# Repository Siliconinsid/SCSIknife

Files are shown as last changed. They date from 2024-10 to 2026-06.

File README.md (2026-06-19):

# SCSIknife

SCSIknife - A compact and versatile SCSI emulator.

SCSIknife is a ZuluSCSI™ PICO OSHW derivative, compatible with the ZuluSCSI™ PICO firmware.

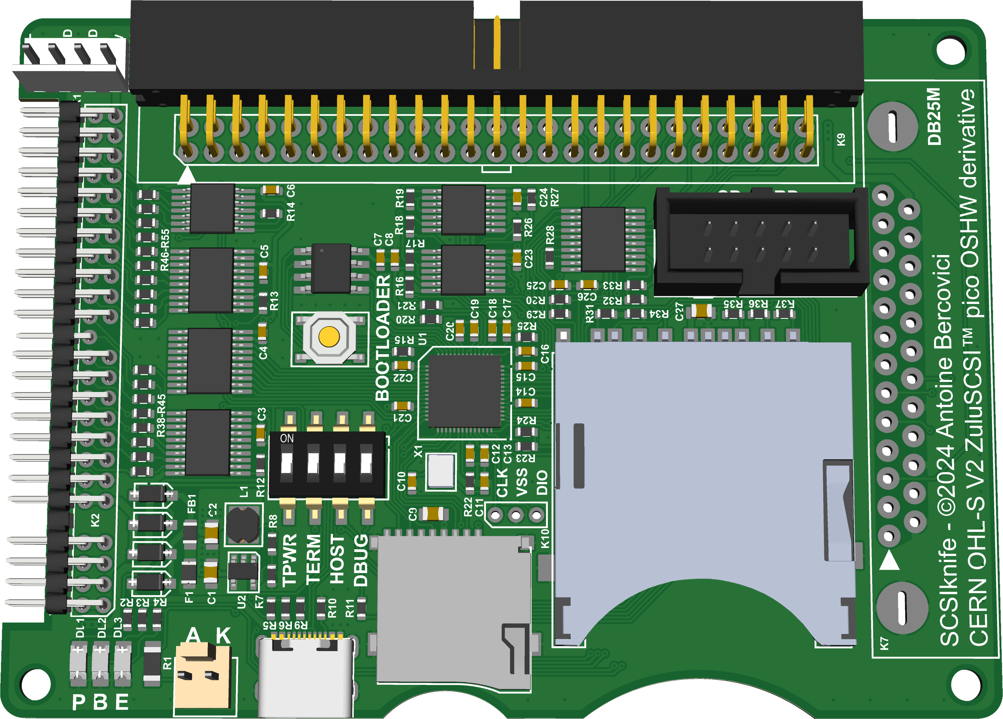
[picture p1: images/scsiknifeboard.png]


SCSIknife has the same compact footprint as a 2.5" hard disk drive, yet provide a rich SCSI connectivity with a male DB25 connector, HE-10 50-pin and 50-pin 2.5" for laptops. Two SD card sockets can accomodate standard SD cards as well as micro SD cards (only one type can be used at a time). A HE-10 10-pin connector expose the SD card signals in order to extend the SD card connector away from SCSIknife.

# Hardware

SCSIknife require 5.0VDC ± 0.5V which can be supplied by the SCSI termination, the 4-pin Berg style connector, the 2.5" SCSI connector, or USB-C.
For host systems not providing SCSI termination power on the bus, SCSIknife can backfeed termination power by enabling the "TPWR" switch.

The HE-10 10-pin SD card extension connector use the following pinout:

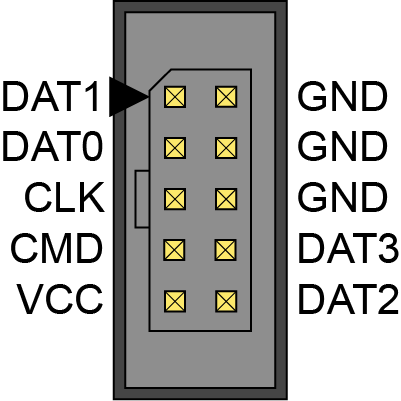
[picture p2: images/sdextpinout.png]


Status LED is connected to RP2040 GPIO16

Error LED is connected to RP2040 GPIO25

SCSI DB25 connector is male, but can be replaced with DB25 female if soldered on the underside of the board.

# Firmware

SCSIknife is 100% compatible with the ZuluSCSI™ PICO firmware.
As such, flashing instructions can be found [there](https://github.com/ZuluSCSI/ZuluSCSI-firmware)

To update the firmware, download the universal `.zip` archive and place it on a SD card, firmware will be updated at power up.
Alternatively, place the PICO version of the `.bin` file on the SD card. Do not use the RP2040 or any RP2350 based versions.
If for some reason SCSIknife is unresponsive or if the wrong firmware is flashed, restore by pressing and holding the “Bootloader” button before plugging in the USB C connection to a computer. SCSIknife will appear as a drive on the desktop. Drop the PICO firmware file in `.uf2` format on the disk and SCSIknife will automatically update and disconnect itself upon completion. 

# Accessories

Andreas has kindly made available 3D printable file for a 3.5" bracket. 
* [Andreas bracket](https://makerworld.com/fr/models/2948116-scsiknife-hdd-bracket)

# Gerber generation

This PCB was designed with Adobe Illustrator, and exported as SVG files.

These SVG files are then converted to Gerber using the following tools:
* [Gerbolyze](https://github.com/jaseg/gerbolyze)
* [svg-to-gerber](https://github.com/Altomare/svg-to-gerber): gerbolyze wrapper + drill file generation

If you need to re-generate gerbers:
```shell
# Illustrator uses 72 DPI instead of the usual 96 for SVG files
svg-to-gerber.py SCSIknife/svg SCSIknife/gerber 72

# If you end up with a negative gerber on some layers, 
# re-run the svg-flatten command seen in logs without -f.
# It seems to behave differently on different setups
```

# License and disclaimer

SCSIknife is based on ZuluSCSI™ PICO OSHW, which can be found here:
* [ZuluSCSI™ Pico OSHW](https://github.com/ZuluSCSI/ZuluSCSI-Pico-OSHW)
* [ZuluSCSI™ Firmware](http://github.com/ZuluSCSI/ZuluSCSI-firmware)

ZuluSCSI™ is a registered trademark of Rabbit Hole Computing.
Rabbit Hole Computing is not responsible for the SCSIknife hardware and does not provide technical support and troubleshooting regarding SCSIknife related issues.

SCSIknife inherits the CERN-OHL-S-2.0 license from ZuluSCSI Pico

See [license.txt](LICENSE.txt)

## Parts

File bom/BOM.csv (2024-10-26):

Designator | Component | Type | Value | Rating | Voltage | Tolerance | Package | Manufacturer | Part number
R1 | Resistor | Thick film | 120Ω | 1/4W | 200V | 1% | 1206 | Vishay Dale | CRCW1206120RFKEA
R2 | Resistor | Thick film | 51Ω | 1/10W | 75V | 1% | 0603 | Vishay Dale | CRCW060351R0FKEA
R3 | Resistor | Thick film | 150Ω | 1/10W | 75V | 1% | 0603 | Vishay Dale | CRCW0603150RFKEA
R4 | Resistor | Thick film | 150Ω | 1/10W | 75V | 1% | 0603 | Vishay Dale | CRCW0603150RFKEA
R5 | Resistor | Thick film | 5.6kΩ | 1/10W | 75V | 1% | 0603 | Vishay Dale | CRCW06035K60FKEA
R6 | Resistor | Thick film | 10kΩ | 1/10W | 75V | 1% | 0603 | Vishay Dale | CRCW060310K0FKEA
R7 | Resistor | Thick film | 20kΩ | 1/10W | 75V | 1% | 0603 | Vishay Dale | CRCW060320K0FKEA
R8 | Resistor | Thick film | 90.9kΩ | 1/10W | 75V | 1% | 0603 | Vishay Dale | CRCW060390K9FKEA
R9 | Resistor | Thick film | 5.1kΩ | 1/10W | 75V | 1% | 0603 | Vishay Dale | CRCW06035K10FKEA
R10 | Resistor | Thick film | 5.1kΩ | 1/10W | 75V | 1% | 0603 | Vishay Dale | CRCW06035K10FKEA
R11 | Resistor | Thick film | 4.7kΩ | 1/10W | 75V | 1% | 0603 | Vishay Dale | CRCW06034K70FKEA
R12 | Resistor | Thick film | 1kΩ | 1/10W | 75V | 1% | 0603 | Vishay Dale | CRCW06031K00FKEA
R13 | Resistor | Thick film | 4.7kΩ | 1/10W | 75V | 1% | 0603 | Vishay Dale | CRCW06034K70FKEA
R14 | Resistor | Thick film | 1kΩ | 1/10W | 75V | 1% | 0603 | Vishay Dale | CRCW06031K00FKEA
R15 | Resistor | Thick film | 1kΩ | 1/10W | 75V | 1% | 0603 | Vishay Dale | CRCW06031K00FKEA
R16 | Resistor | Thick film | 1kΩ | 1/10W | 75V | 1% | 0603 | Vishay Dale | CRCW06031K00FKEA
R17 | Resistor | Thick film | 4.7kΩ | 1/10W | 75V | 1% | 0603 | Vishay Dale | CRCW06034K70FKEA
R18 | Resistor | Thick film | 1kΩ | 1/10W | 75V | 1% | 0603 | Vishay Dale | CRCW06031K00FKEA
R19 | Resistor | Thick film | 4.7kΩ | 1/10W | 75V | 1% | 0603 | Vishay Dale | CRCW06034K70FKEA
R20 | Resistor | Thick film | 27Ω | 1/10W | 75V | 1% | 0603 | Vishay Dale | CRCW060327R0FKEA
R21 | Resistor | Thick film | 27Ω | 1/10W | 75V | 1% | 0603 | Vishay Dale | CRCW060327R0FKEA
R22 | Resistor | Thick film | 1kΩ | 1/10W | 75V | 1% | 0603 | Vishay Dale | CRCW06031K00FKEA
R23 | Resistor | Thick film | 1kΩ | 1/10W | 75V | 1% | 0603 | Vishay Dale | CRCW06031K00FKEA
R24 | Resistor | Thick film | 4.7kΩ | 1/10W | 75V | 1% | 0603 | Vishay Dale | CRCW06034K70FKEA
R25 | Resistor | Thick film | 200Ω | 1/10W | 75V | 1% | 0603 | Vishay Dale | CRCW0603200RFKEA
R26 | Resistor | Thick film | 4.7kΩ | 1/10W | 75V | 1% | 0603 | Vishay Dale | CRCW06034K70FKEA
R27 | Resistor | Thick film | 4.7kΩ | 1/10W | 75V | 1% | 0603 | Vishay Dale | CRCW06034K70FKEA
R28 | Resistor | Thick film | 110Ω | 1/10W | 75V | 1% | 0603 | Vishay Dale | CRCW0603110RFKEA
R29 | Resistor | Thick film | 1kΩ | 1/10W | 75V | 1% | 0603 | Vishay Dale | CRCW06031K00FKEA
R30 | Resistor | Thick film | 4.7kΩ | 1/10W | 75V | 1% | 0603 | Vishay Dale | CRCW06034K70FKEA
R31 | Resistor | Thick film | 4.7kΩ | 1/10W | 75V | 1% | 0603 | Vishay Dale | CRCW06034K70FKEA
R32 | Resistor | Thick film | 1kΩ | 1/10W | 75V | 1% | 0603 | Vishay Dale | CRCW06031K00FKEA
R33 | Resistor | Thick film | 1kΩ | 1/10W | 75V | 1% | 0603 | Vishay Dale | CRCW06031K00FKEA
R34 | Resistor | Thick film | 4.7kΩ | 1/10W | 75V | 1% | 0603 | Vishay Dale | CRCW06034K70FKEA
R35 | Resistor | Thick film | 4.7kΩ | 1/10W | 75V | 1% | 0603 | Vishay Dale | CRCW06034K70FKEA
R36 | Resistor | Thick film | 4.7kΩ | 1/10W | 75V | 1% | 0603 | Vishay Dale | CRCW06034K70FKEA
R37 | Resistor | Thick film | 4.7kΩ | 1/10W | 75V | 1% | 0603 | Vishay Dale | CRCW06034K70FKEA
R38 | Resistor | Thick film | 110Ω | 1/10W | 75V | 1% | 0603 | Vishay Dale | CRCW0603110RFKEA
R39 | Resistor | Thick film | 110Ω | 1/10W | 75V | 1% | 0603 | Vishay Dale | CRCW0603110RFKEA
R40 | Resistor | Thick film | 110Ω | 1/10W | 75V | 1% | 0603 | Vishay Dale | CRCW0603110RFKEA
R41 | Resistor | Thick film | 110Ω | 1/10W | 75V | 1% | 0603 | Vishay Dale | CRCW0603110RFKEA
R42 | Resistor | Thick film | 110Ω | 1/10W | 75V | 1% | 0603 | Vishay Dale | CRCW0603110RFKEA
R43 | Resistor | Thick film | 110Ω | 1/10W | 75V | 1% | 0603 | Vishay Dale | CRCW0603110RFKEA
R44 | Resistor | Thick film | 110Ω | 1/10W | 75V | 1% | 0603 | Vishay Dale | CRCW0603110RFKEA
R45 | Resistor | Thick film | 110Ω | 1/10W | 75V | 1% | 0603 | Vishay Dale | CRCW0603110RFKEA
R46 | Resistor | Thick film | 110Ω | 1/10W | 75V | 1% | 0603 | Vishay Dale | CRCW0603110RFKEA
R47 | Resistor | Thick film | 110Ω | 1/10W | 75V | 1% | 0603 | Vishay Dale | CRCW0603110RFKEA
R48 | Resistor | Thick film | 110Ω | 1/10W | 75V | 1% | 0603 | Vishay Dale | CRCW0603110RFKEA
R49 | Resistor | Thick film | 110Ω | 1/10W | 75V | 1% | 0603 | Vishay Dale | CRCW0603110RFKEA
R50 | Resistor | Thick film | 110Ω | 1/10W | 75V | 1% | 0603 | Vishay Dale | CRCW0603110RFKEA
R51 | Resistor | Thick film | 110Ω | 1/10W | 75V | 1% | 0603 | Vishay Dale | CRCW0603110RFKEA
R52 | Resistor | Thick film | 110Ω | 1/10W | 75V | 1% | 0603 | Vishay Dale | CRCW0603110RFKEA
R53 | Resistor | Thick film | 110Ω | 1/10W | 75V | 1% | 0603 | Vishay Dale | CRCW0603110RFKEA
R54 | Resistor | Thick film | 110Ω | 1/10W | 75V | 1% | 0603 | Vishay Dale | CRCW0603110RFKEA
R55 | Resistor | Thick film | 110Ω | 1/10W | 75V | 1% | 0603 | Vishay Dale | CRCW0603110RFKEA
C1 | Capacitor | MLCC | 22µF | X5R | 16V | 20% | 0805 | Samsung | CL10A226MO7JZNC
C2 | Capacitor | MLCC | 10µF | X7R | 25V | 10% | 0805 | Murata | GRM21BZ71E106KE15L
C3 | Capacitor | MLCC | 100nF | X7R | 25V | 10% | 0603 | Vishay Vitramon | VJ0603Y104KXXCW1BC
C4 | Capacitor | MLCC | 100nF | X7R | 25V | 10% | 0603 | Vishay Vitramon | VJ0603Y104KXXCW1BC
C5 | Capacitor | MLCC | 100nF | X7R | 25V | 10% | 0603 | Vishay Vitramon | VJ0603Y104KXXCW1BC
C6 | Capacitor | MLCC | 100nF | X7R | 25V | 10% | 0603 | Vishay Vitramon | VJ0603Y104KXXCW1BC
C7 | Capacitor | MLCC | 100nF | X7R | 25V | 10% | 0603 | Vishay Vitramon | VJ0603Y104KXXCW1BC
C8 | Capacitor | MLCC | 2.2µF | X7R | 25V | 10% | 0603 | Murata | GRM188Z71E225KE43D
C9 | Capacitor | MLCC | 10µF | X7R | 25V | 10% | 0805 | Murata | GRM21BZ71E106KE15L
C10 | Capacitor | MLCC | 15pF | C0G | 25V | 2% | 0603 | Vishay Vitramon | VJ0603A150GXXCW1BC
C11 | Capacitor | MLCC | 15pF | C0G | 25V | 2% | 0603 | Vishay Vitramon | VJ0603A150GXXCW1BC
C12 | Capacitor | MLCC | 100nF | X7R | 25V | 10% | 0603 | Vishay Vitramon | VJ0603Y104KXXCW1BC
C13 | Capacitor | MLCC | 100nF | X7R | 25V | 10% | 0603 | Vishay Vitramon | VJ0603Y104KXXCW1BC
C14 | Capacitor | MLCC | 100nF | X7R | 25V | 10% | 0603 | Vishay Vitramon | VJ0603Y104KXXCW1BC
C15 | Capacitor | MLCC | 100nF | X7R | 25V | 10% | 0603 | Vishay Vitramon | VJ0603Y104KXXCW1BC
C16 | Capacitor | MLCC | 2.2µF | X7R | 25V | 10% | 0603 | Murata | GRM188Z71E225KE43D
C17 | Capacitor | MLCC | 2.2µF | X7R | 25V | 10% | 0603 | Murata | GRM188Z71E225KE43D
C18 | Capacitor | MLCC | 2.2µF | X7R | 25V | 10% | 0603 | Murata | GRM188Z71E225KE43D
C19 | Capacitor | MLCC | 100nF | X7R | 25V | 10% | 0603 | Vishay Vitramon | VJ0603Y104KXXCW1BC
C20 | Capacitor | MLCC | 100nF | X7R | 25V | 10% | 0603 | Vishay Vitramon | VJ0603Y104KXXCW1BC
C21 | Capacitor | MLCC | 100nF | X7R | 25V | 10% | 0603 | Vishay Vitramon | VJ0603Y104KXXCW1BC
C22 | Capacitor | MLCC | 100nF | X7R | 25V | 10% | 0603 | Vishay Vitramon | VJ0603Y104KXXCW1BC
C23 | Capacitor | MLCC | 100nF | X7R | 25V | 10% | 0603 | Vishay Vitramon | VJ0603Y104KXXCW1BC
C24 | Capacitor | MLCC | 100nF | X7R | 25V | 10% | 0603 | Vishay Vitramon | VJ0603Y104KXXCW1BC
C25 | Capacitor | MLCC | 12pF | C0G | 25V | 2% | 0603 | Vishay Vitramon | VJ0603A120GXXCW1BC
C26 | Capacitor | MLCC | 100nF | X7R | 25V | 10% | 0603 | Vishay Vitramon | VJ0603Y104KXXCW1BC
C27 | Capacitor | MLCC | 10µF | X7R | 25V | 10% | 0805 | Murata | GRM21BZ71E106KE15L
F1 | PTC | Polymer | 750mA | 50A | 12V |  | 0805 | Bourns | MF-PSML075/12-2
FB1 | Ferrite |  | 300mΩ | 500mA |  |  | 0805 | Laird | HZ0805E601R-10
L1 | Inductor |  | 2.2µH | 1.71A |  |  |  | Würth Elektronik | 7447732022
X1 | Crystal |  | 12MHz |  |  |  |  | Abracon | ABM8AIG-12.000MHZ-12-2Z-T3
D1 | Diode | Schottky | B5819W | 1A | 40V |  | SOD123 | Micro Commercial | B5819W-TP
D2 | Diode | Schottky | B5819W | 1A | 40V |  | SOD123 | Micro Commercial | B5819W-TP
D3 | Diode | Schottky | B5819W | 1A | 40V |  | SOD123 | Micro Commercial | B5819W-TP
D4 | Diode | Schottky | B5819W | 1A | 40V |  | SOD123 | Micro Commercial | B5819W-TP
DL1 | Diode | LED | Yellow-green | 20mA | 2V |  | 1206 | Würth Elektronik | 150120VS75000
DL2 | Diode | LED | Yellow | 20mA | 2V |  | 1206 | Würth Elektronik | 150120YS75000
DL3 | Diode | LED | Red | 20mA | 2V |  | 1206 | Würth Elektronik | 150120RS75000
U1 | Integrated circuit | Microcontroller | RP2040 |  |  |  | QFN56 | Raspberry Pi | SC0914(13)
U2 | Integrated circuit | Switching regulator | RT5796A | 1.5A | Adjustable |  | SOT23-5 | Richtek | RT5796AHGJ5
U3 | Integrated circuit | Bus transceiver | SN74LVT245 |  |  |  | TSSOP20 | Texas Instruments | SN74LVT245BPWR
U4 | Integrated circuit | Bus transceiver | SN74LVT245 |  |  |  | TSSOP20 | Texas Instruments | SN74LVT245BPWR
U5 | Integrated circuit | Bus transceiver | SN74LVT245 |  |  |  | TSSOP20 | Texas Instruments | SN74LVT245BPWR
U6 | Integrated circuit | Buffer | SN74LVT125 |  |  |  | TSSOP14 | Texas Instruments | SN74LVT125PWR
U7 | Integrated circuit | Flash memory | W25Q16 |  |  |  | SOIC8 | Winbond | W25Q16JVSSIQ
U8 | Integrated circuit | Buffer | SN74LVT125 |  |  |  | TSSOP14 | Texas Instruments | SN74LVT125PWR
U9 | Integrated circuit | Buffer | SN74LVT125 |  |  |  | TSSOP14 | Texas Instruments | SN74LVT125PWR
U10 | Integrated circuit | Bus transceiver | SN74LVT245 |  |  |  | TSSOP20 | Texas Instruments | SN74LVT245BPWR
S1 | Switch | Tactile switch |  |  |  |  |  | C&K | PTS526 SK15 SMTR2 LFS
S2 | Switch | DIP switch | 4 positions |  |  |  | DIP8 | CUI Devices | DS04-254-2-04BK-SMT
K1 | Connector | Header | 4 positions | Male |  | 2.50mm |  | TE Connectivity | 172732-4
K2 | Connector | Header | 50 positions | Male |  | 2mm |  | Sullins Connector Solutions | NRPN252PARN-RC
K3 | Connector | Header | 2 positions | Male |  | 2.54mm |  | Molex | 0022272021
K4 | Connector | USB-C |  |  |  |  |  | Amphenol | 12402012E212A
K5 | Connector | Micro SD card |  |  |  |  |  | CUI Devices | MSD-1-A
K6 | Connector | SD Card |  |  |  |  |  | CUI Devices | SD-2-A
K7 | Connector | DB-25 |  | Male |  |  |  | Adam Tech | DB25-PL-24
K8 | Connector | Header | 10 positions | Male |  | 2.54mm |  | Sullins Connector Solutions | SBH11-PBPC-D05-ST-BK
K9 | Connector | Header | 50 positions | Male |  | 2.54mm |  | Sullins Connector Solutions | SBH11-PBPC-D25-RA-BK

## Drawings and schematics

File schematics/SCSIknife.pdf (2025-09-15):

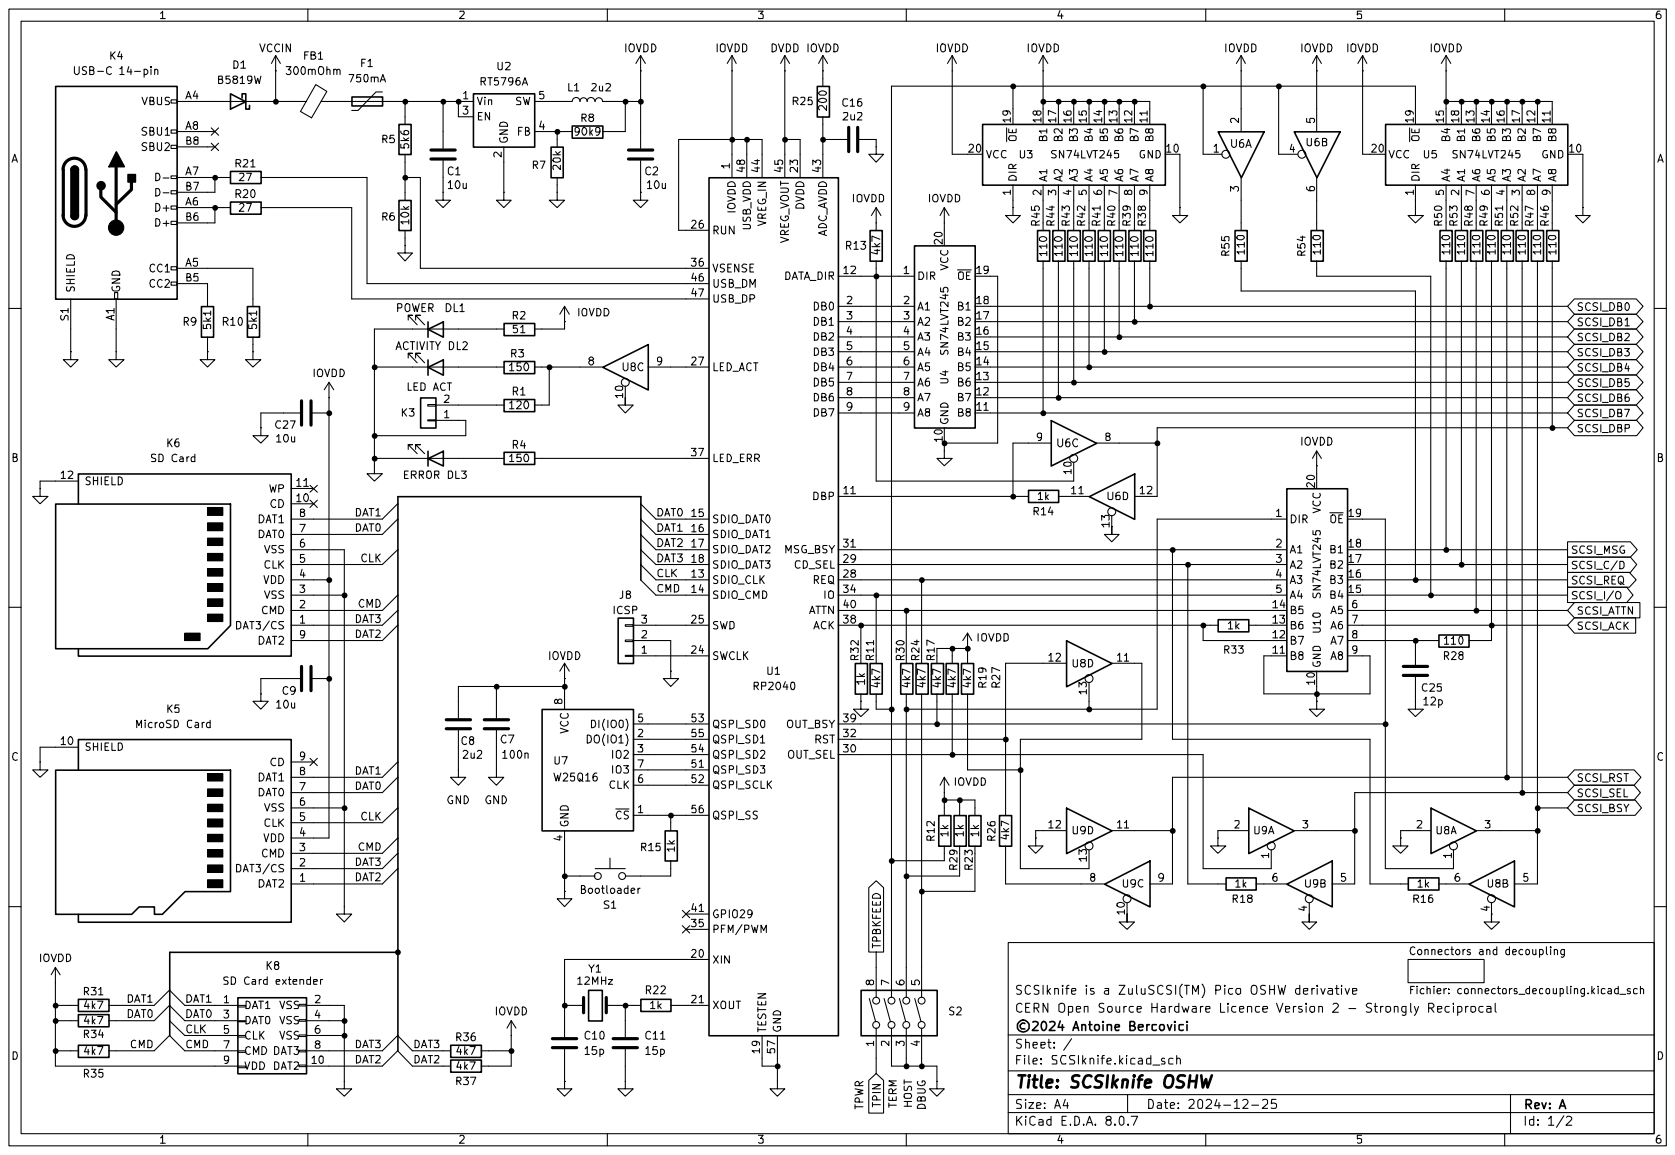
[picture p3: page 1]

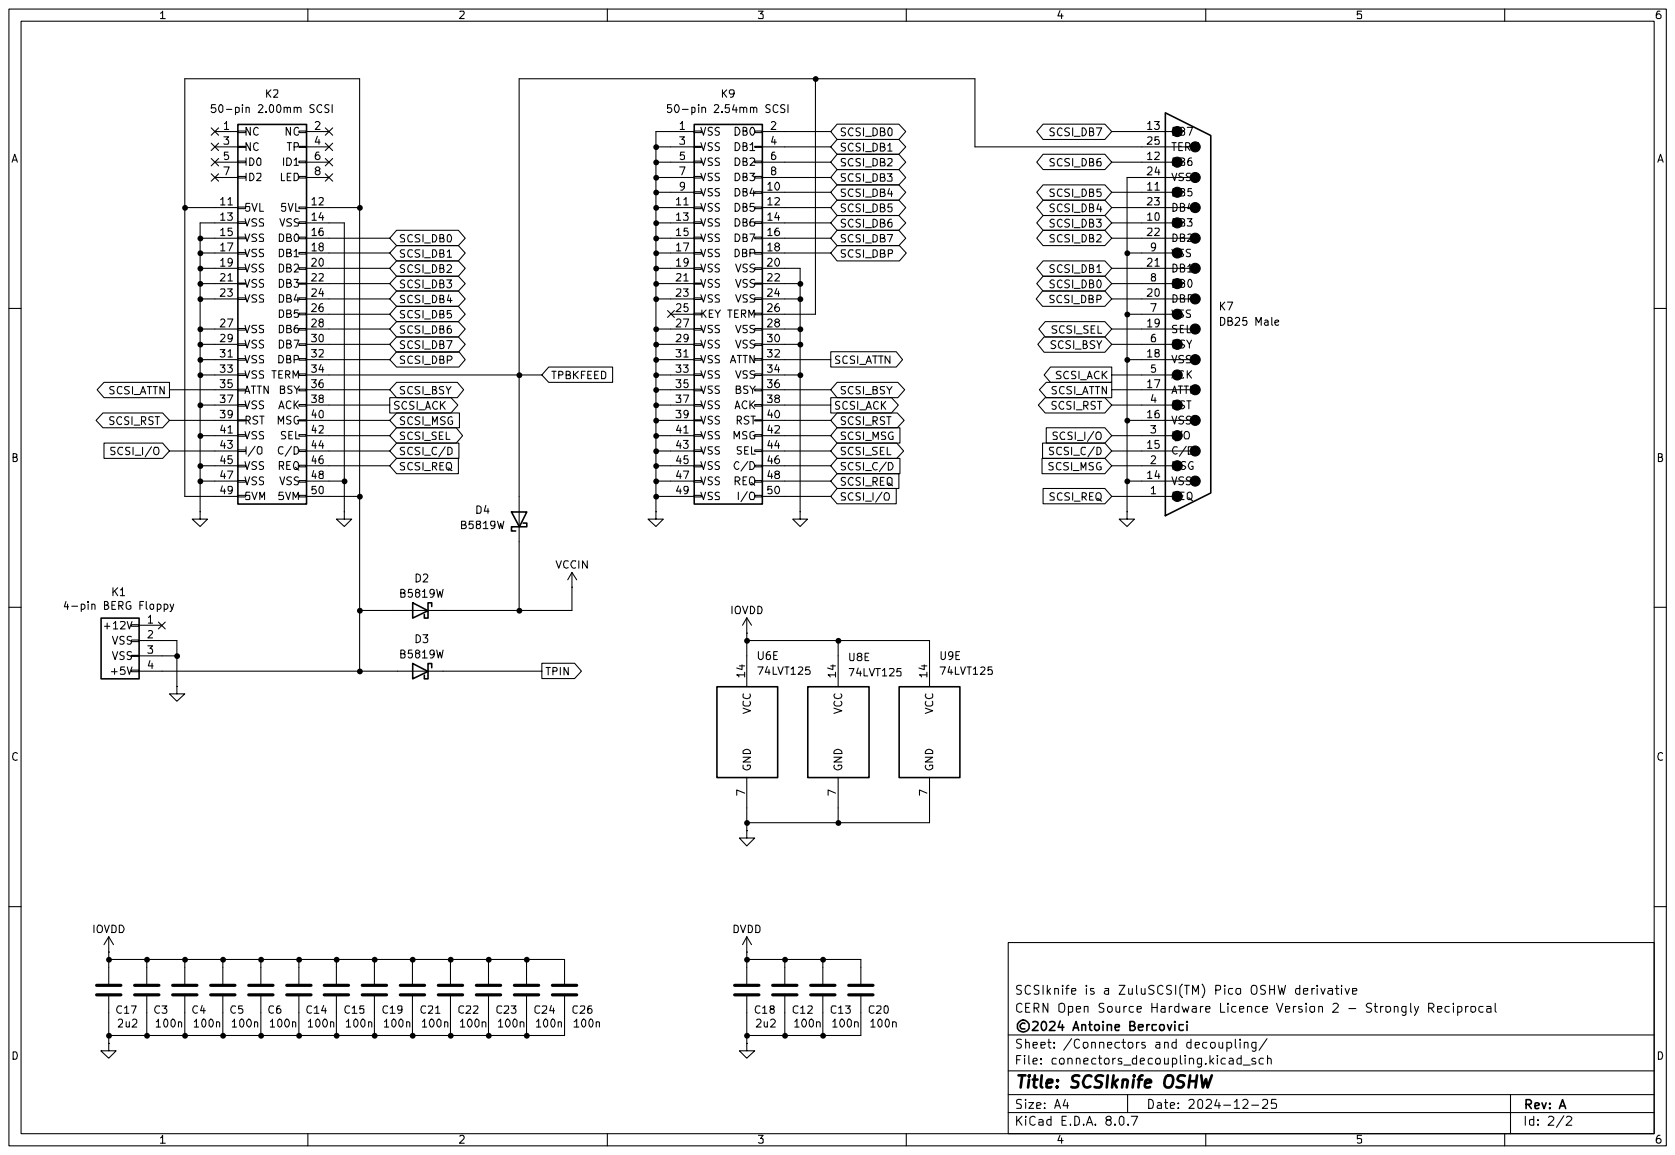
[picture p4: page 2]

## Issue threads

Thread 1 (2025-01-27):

Question: is SCSIknife only for mass storage, or also for other SCSI devices ?

liotier, 2025-01-27:
Hello, I'm looking for an adapter between a contemporary PC (USB, PCIE etc.) and an elderly Nikon LS-30 scanner. Could the SCSIKnife act as a generic SCSI adapter, or does it only work for getting to an SCSI drive as USB mass storage ?

Siliconinsid, 2025-01-27:
Hello and thanks for reaching out.
It will only work for mass storage devices. You may have issues running your scanner on a modern system beyond just the lack of the SCSI interface, as the driver software also needs to run in a modern OS. In such case the best solution is to keep a legacy computer dedicated to the use of the scanner.
Best,
Antoine.

liotier, 2025-01-27:
Thank you for that extremely quick answer !

Closed 2025-01-27.

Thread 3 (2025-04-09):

Possibility to update the Firmware via SD-Card?

explit7, 2025-04-09:
Hello @Siliconinsid
SCSI Knife should be fully compatible with ZuluSCSI-Firmware.
[Here](https://github.com/ZuluSCSI/ZuluSCSI-firmware) they write that there exist custom boot loader which can pick-up Firmware files directly from the SD-Card.
Is it also possible with SCSIKnife?

The case is, that i have an Apple PowerBook 180. My SD-Card-Slot is accessible from the outside of the Powerbook.
But when i need to update Firmware, i need to disassembly the whole powerbook, to connect the USB cable and push the boot button.
I want to avoid it, since, the Hardware is old and Plastic will not last multiple Disassembly-Assembly sessions.

Thanks

Siliconinsid, 2025-04-09:
Hello, it is also upgradeable through the SD-card, as the ZuluSCSI-Firmware does support this functionality.
Best

explit7, 2025-04-09:
Great, so issue can be closed, thanks

Closed 2025-04-09.

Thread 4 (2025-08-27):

Issue with data corruption on SD card (parity errors, OS unable to mount root, etc)

vom513, 2025-08-27:
Hello,

I have a SK SCA.  I updated to:

https://github.com/ZuluSCSI/ZuluSCSI-firmware/releases/tag/v2025.08.26

And afterwards I would get parity errors in kernel log (this is NetBSD 10.1 on a Sparc SS20).  Also the machine would no longer mount root.

I reverted to 2025.08.19 and things seem back to normal.  I have no data to back this up re: root cause, but one thing that caught my eye in the release notes is:

Standardize board system clock frequencies by @morio in https://github.com/ZuluSCSI/ZuluSCSI-firmware/pull/638

Thanks for any insight.

vom513, 2025-08-27:
FYI I also opened an issue over on the ZS side:

https://github.com/ZuluSCSI/ZuluSCSI-firmware/issues/647

Siliconinsid, 2025-08-28:
At the moment it seems that the issue is related to the specific SD card used and not to SCSIKnife, nor the new 2025.08.26.

vom513, 2025-08-28:
> At the moment it seems that the issue is related to the specific SD card used and not to SCSIKnife, nor the new 2025.08.26.

Yes I will try some other SD cards (diff. manufacturers).  We can close this - thanks.

Closed 2025-08-28.

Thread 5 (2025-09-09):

Termination voltage too low causing unreliable operation on Amiga/SCSI-Kit IV

screwtop, 2025-09-09:
I have a SCSIknife that I'm trying to use with an Amiga 1200 with a phase5 SCSI-Kit IV. The hardware looks beautifully designed and assembled, but for some reason(s) I have not been able to get it to work reliably, particularly with recent ZuluSCSI firmware and when using synchronous SCSI mode. What typically happens is that the drive activity light remains on while `scsi_accel_rp2040_finishRead timeout` and/or `WATCHDOG TIMEOUT, attempting bus reset` errors appear in the `zululog.txt`. Even after rebooting the Amiga, the hangs and delays continue, and I have to power-cycle the SCSIknife to get it to reset (though replugging the SD card sometimes works).

I've also tested the SCSIknife on a Linux PC with an Adaptec 39160 card, and it seems to work fine there, which I guess points to there being something amiss with the Amiga (maybe cabling, supply or I/O voltages, timing issues, software issues, ...?).

I've tried a variety of cables, termination options, and a couple of different SD cards (an Apacer 4 GB Class 6 full-size SD card, and a SanDisk 32 GB Class 10 microSD card). I think I identified one bad ribbon cable in the process. I also tested powering the SCSIknife from bus power only, from USB-C, and using the Berg floppy connector. There have been times when it will work at full speed (achieving over 8 MB/s) and for many hours, but often when I repeat a "presumed-good" configuration it may fail to work. I'm using [`devtest`](https://github.com/cdhooper/amiga_devtest) to test just the block device, independently of the filesystem.

I've documented a lot of my troubleshooting over at the ZuluSCSI firmware site [here](https://github.com/ZuluSCSI/ZuluSCSI-firmware/discussions/659); there may be useful details there too.

## System Details

Hardware:
 - SCSIknife
 - SD card: SanDisk Ultra microSDHC UHS-I card, 32 GiB
 - Amiga 1200
 - Blizzard 1260 accelerator (50 MHz 68060)
 - SCSI-Kit IV host adapter (FAS216)
 - DB25 to CN50 cable, < 1 m (I've tried a couple of different ones)
 - A couple of late-1990s drive enclosures
 - Active CN50 terminator (also tried the SCSIknife's internal termination)

Software:
 - ZuluSCSI firmware 25.08.19, 25.08.26, 25.09.04
 - Amiga Kickstart V40.68
 - Workbench V39.29
 - `1230scsi.device` V8.5

I have a multimeter, a bench power supply and a 50 MHz oscilloscope for hardware troubleshooting, but no logic analyser. I recently wondered about power supply stability, and did some testing. Running (successfully) with the PC/Adaptec card, I see:
 - 4.8 V at TERMPWR on the SCSIknife board
 - 4.4 V at IOVDD (is this a little high?)

On the Amiga, the measured voltages are:
 - 4.2 V at TERMPWR
 - 3.8 V at IOVDD

I did mean to check what firmware version the SCSIknife would have shipped with. Thanks for any troubleshooting advice you can offer!

screwtop, 2025-09-09:
Thanks for the very fast reply! The IOVDD measurement was taken at C1, on the side nearer the drive activity LED header.

screwtop, 2025-09-10:
Ah! That makes sense then. I just now measured at capacitor "C2" (really C1) next to the inductor and got 3.28 V, and that didn't change as I varied VIN, so that's good news. I couldn't find a dropout voltage spec in the RT5796A datasheet, but I think I can conclude that the SCSI bus power on this Amiga is marginal for the SCSIknife, and I should use an external +5 V supply.

Also, I've just flashed the ZuluSCSI v25.09.09 hotfix firmware posted over at [my discussion](https://github.com/ZuluSCSI/ZuluSCSI-firmware/discussions/659) and it looks like the timing changes have significantly improved things on my Amiga - I'm reliably seeing over 8 MB/s in `devtest` and it has done hundreds of loops without error, though there is still the occasional hang. Could it be worth adding a bulk capacitor somewhere on the SCSIknife, just to rule that out as a factor?

Siliconinsid, 2025-09-10:
3.28V is normal, for DC/DC the minimum operating voltage is usually Vout + Vref, which is 0.6V. So indeed, you are operating at the margin at 3.8V.

Note that I had other customer experiencing solid LED ON on samplers because VTerm supplied was too weak, and things were solved by using an external supply.

I do not think that bulk capacitance is an issue and will improve much of anything, but you can try to rule it out by adding anything from 100 to 1000uF. I have hundreds of SCSIknife working well in various systems and the current decoupling is up to spec as far as I know.

One of the major source of troubles however is SD cards, which are of varying quality. If you have tried more than one, but not more than two, I would look into that.

I will update the schematics for the C1/C2 designator swap.

screwtop, 2025-09-30:
I made a useful breakthrough over the weekend after opening my A1200 and doing some work on the internal SCSI cabling and connectors. I've updated [my ZuluSCSI firmware discussion](https://github.com/ZuluSCSI/ZuluSCSI-firmware/discussions/659) with details, but it seems the cable was being pinched/scrunched and the connectors perhaps benefited from some cleaning.

My troubleshooting efforts were complicated by the inadequate termination power on the Amiga's SCSI-Kit IV and the varying sensitivity to the cabling/signalling issue among the different ZuluSCSI firmware revisions.

My remaining problem is that file write/create operations on the Amiga are very slow, despite the block-level testing with `devtest` showing at least 3 MB/s. I'll see what I can figure out there.

Thank you so much for your help, and for the beautiful hardware!

Closed 2025-09-30.

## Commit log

2024-10-28 Added connector pinout and main description
2024-12-31 Added schematics
    [SCSIknife.kicad_sch, connectors_decoupling.kicad_sch]
2025-01-22 SDcard extender added
    [extender.drl, extender.gbl, extender.gbo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]
2025-09-15 Correction to schematics
    [SCSIknife.kicad_sch]
